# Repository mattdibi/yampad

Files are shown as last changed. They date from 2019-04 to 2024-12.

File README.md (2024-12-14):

<p align="center">
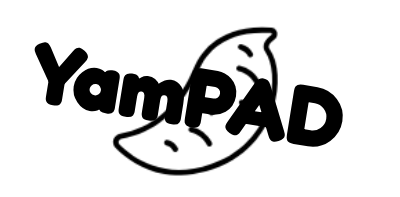
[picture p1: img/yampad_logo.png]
Yampad logo

QMK

</p>

<h3 align="center">The Yampad project repository</h3>

<div align="center">

[]()




</div>

---

The Yampad project is an open-source, [QMK (Quantum Mechanical Keyboard Firmware)](https://github.com/qmk/qmk_firmware) powered, hot-swappable, RGB-backlighted, OLED featured, mechanical numpad. This repository will be used to share information about the project and instruction on how to use and assemble the Yampad.

<p align="center">
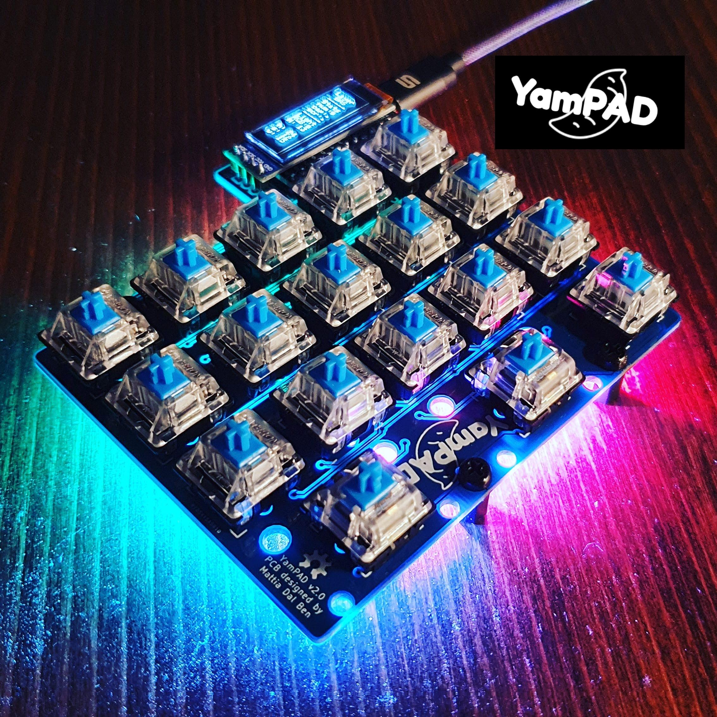
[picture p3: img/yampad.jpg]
Yampad PCB

</p>

**Designer's bio**: [Mattia Dal Ben (aka u/TiaMaT102)](mailto:matthewdibi@gmail.com) obtained a master's degree in Electrical Engineering with a specialization in Computer Science at the University of Udine. Currently works as a Software Engineer in R&D department for a big IoT and Embedded Computers company.

## Table of contents

- [Rationale](#rationale)
- [Default Layout](#default-layout)
- [Bill of materials](#bill-of-materials)
- [Assembly guide](#assembly-guide)
- [Firmware](#firmware)

## Rationale

<p align="center">
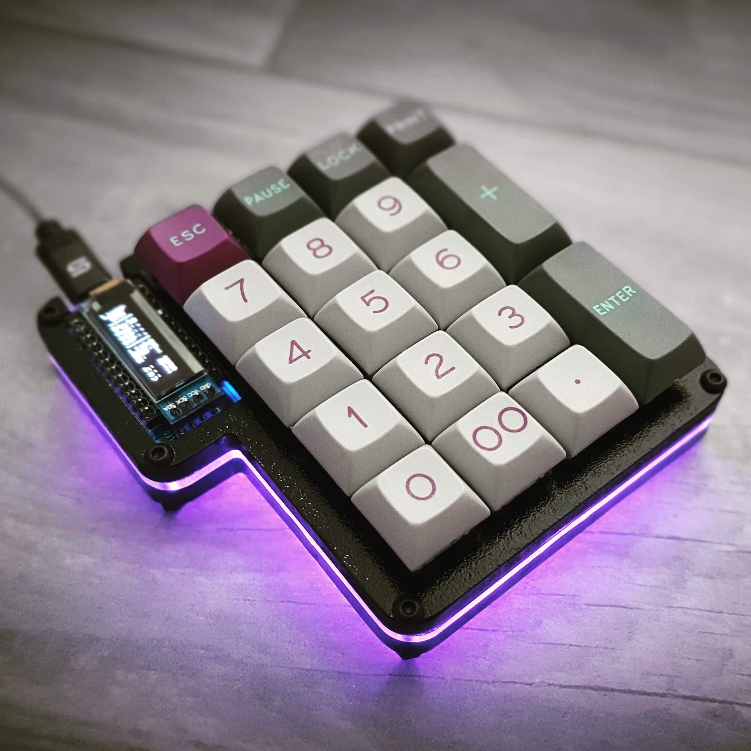
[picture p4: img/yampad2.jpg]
Yampad v2

</p>

The Yampad is a Macropad/Numpad which uses Cherry MX style mechanical switches laid out in the usual numeric pad layout. The only difference comes from the bottom row, which uses a 4 keys configuration, thus enabling the use of the macropad as a nav cluster.

The name comes from the acronym: **Y**et **A**nother **M**echanical num**PAD**, referring to the disruptive and innovative nature of the project.

The main goal of this project is to have a cheap, easy-to-build, feature-rich numpad which is completely open source.

Features:

- Cheap to build: the PCB can be manufactured for less than 1\$ per piece.
- Easy to source components.
- Easy to build.
- Hot swappable keys using _Kailh PCB sockets_.
- Arduino Pro Micro powered.
- QMK compatible.
- RGB backlighting support (optional).
- OLED 0.91" screen (optional).
- Completely open-source.

#### Useful links

- [YamPAD on Hackaday.io](https://hackaday.io/project/163491-yampad-feature-packed-open-source-macropad)

## Default Layout

<p align="center">
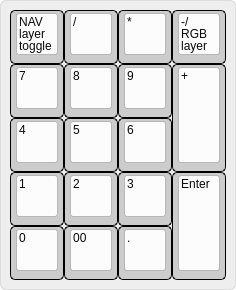
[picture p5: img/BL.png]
Layer 1 Yampad

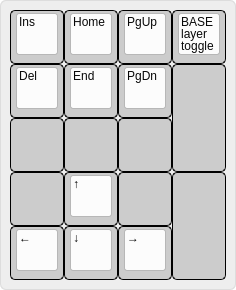
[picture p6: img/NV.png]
Layer 2 Yampad

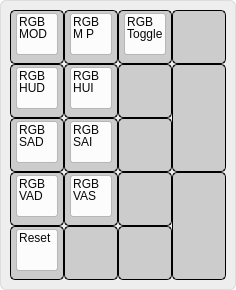
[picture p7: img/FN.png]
Layer 3 Yampad

</p>

## Bill of materials

| Qty | Item | Notes |
| --- | --- | --- |
| 1 | Arduino Pro Micro (ATmega32u4) | a.k.a. SparkFun Pro Micro |
| 18  | Cherry MX compatible swtiches | |
| 18  | SOD-123 1N4148/1N4148W diodes | |
| 18  | Kailh PCB sockets CPG151101S11 | |
| 9 | WS2812B RGB LEDs | Optional |
| 9 | SMD 0805 100nF capacitors | Optional (only required if WS2812B are installed) |
| 1 | I2C 0.91" 128\*32 OLED Display Module | The ones using SSD1306 driver IC over I2C |
| 1 | 6mm\*6mm button switch | |
| 1 | YamPAD PCB | [Order from PCBWay](https://www.pcbway.com/project/shareproject/YamPAD_mechanical_numpad.html) |
| 5 | M3 screws | |

## Assembly guide

There's no wrong order for the YamPAD assembly with the exception of the Arduino/OLED/ResetButton. Here I will suggest an order because I found more comfortable to solder the components this way.

1. Start with soldering the **WS2812 LEDs**. Start by applying solder to a pad, then heat it up while adding the component, finally solder the remaining pads.
2. Now add the **0805 100nF caps**. Use the same technique as before.
3. Add the **1N4148 diodes**.
4. Add the **CPG151101S11 Kailh PCB sockets**.
5. Add the **reset 6mm button switch**.
6. Add some electrical tape just to be sure.
7. Add the **Arduino Pro Micro** bottom side up.
8. Add the **OLED screen**
9. Move to the firmware section and you should be set!

### Assembly details

#### Step 1: WS2812 assembly

<p align="left">The LEDs have a direction, this is indicated by a small cut out corner showing a triangle on the LED itself that must align with a corner indicated on the PCB as a visible corner angle. Top left on images below.</p>
<p align="center">
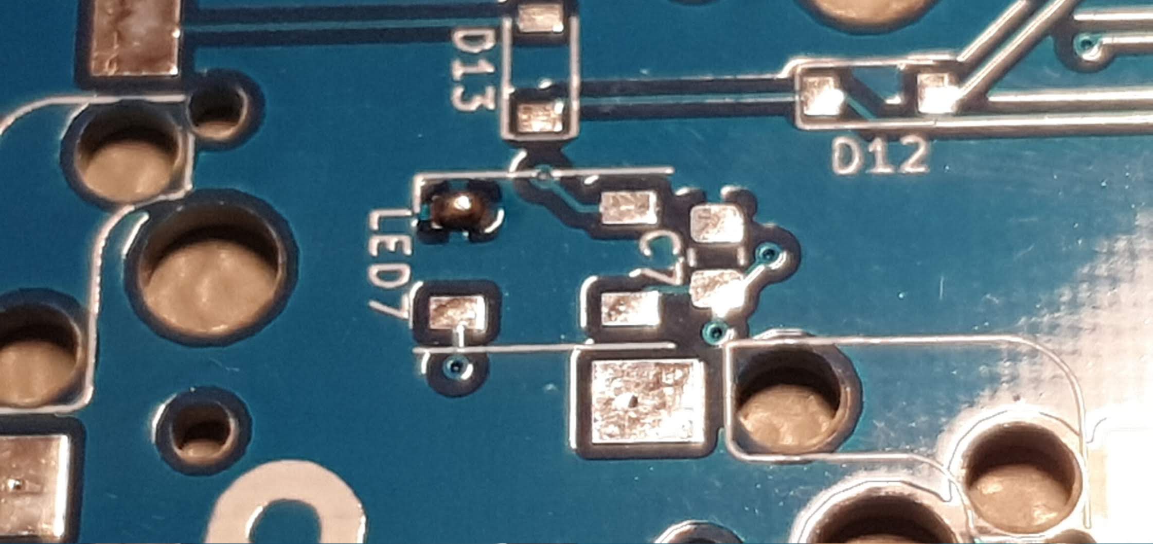
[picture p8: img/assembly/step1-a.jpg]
Step 1-a

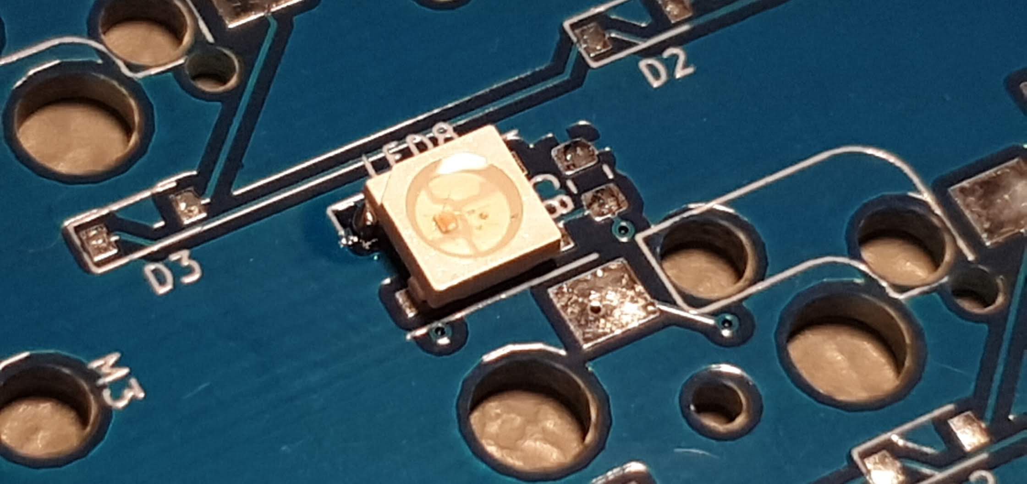
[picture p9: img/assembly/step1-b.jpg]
Step 1-b

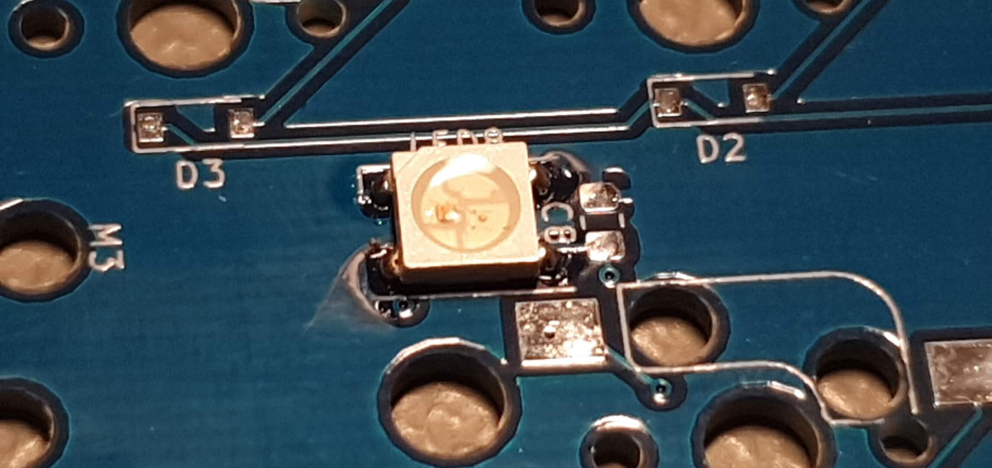
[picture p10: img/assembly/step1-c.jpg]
Step 1-c

</p>

#### Step 2: Capacitors assembly

<p align="center">
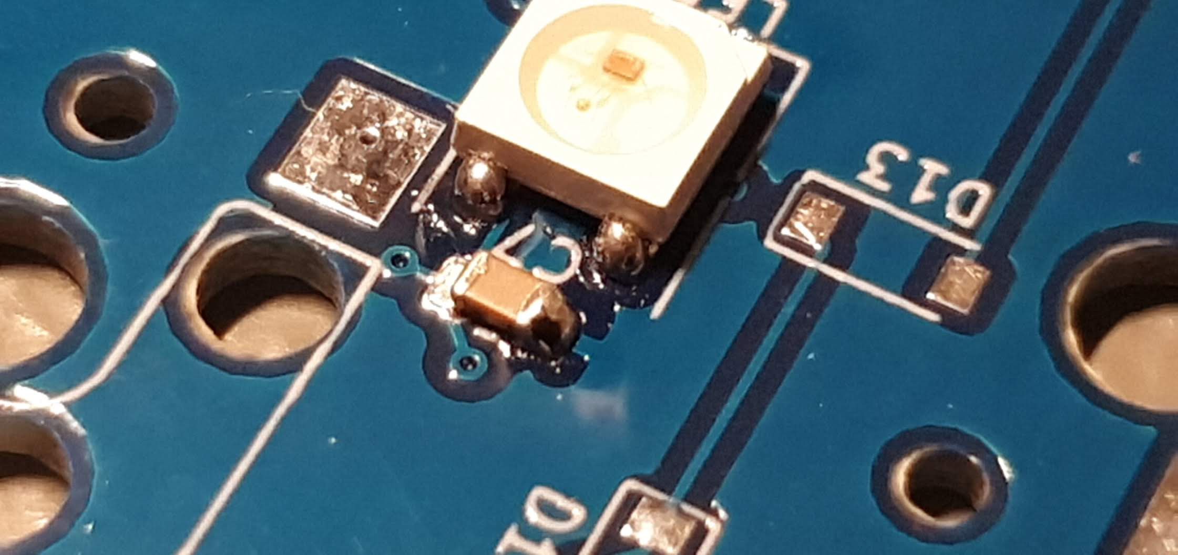
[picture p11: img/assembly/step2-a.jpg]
Step 2-a

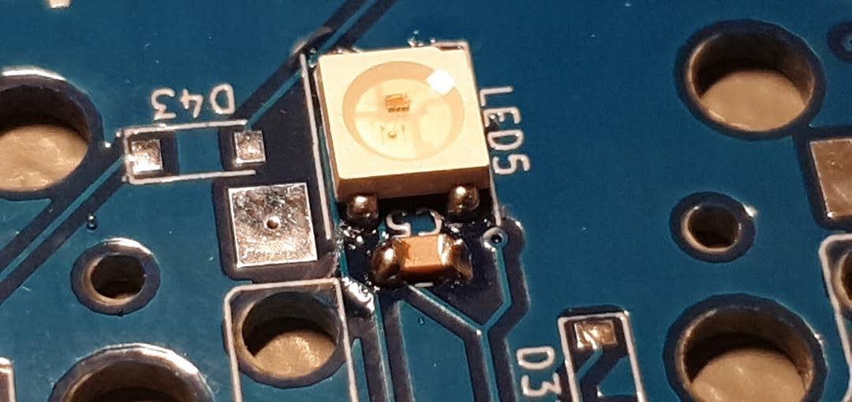
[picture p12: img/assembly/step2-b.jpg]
Step 2-b

</p>

#### Step 3: Diodes assembly

<p align="left">The diodes have a direction, the side indicated by the line on the diode must align to the closed side of the shape on the PCB. Left on the three images below.</p>
<p align="center">
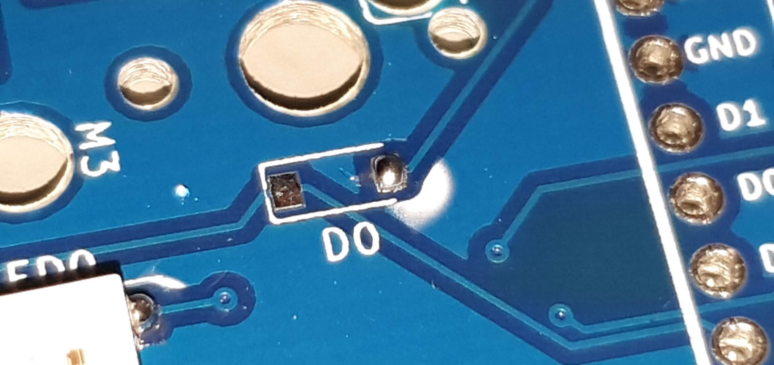
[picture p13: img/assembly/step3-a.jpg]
Step 3-a

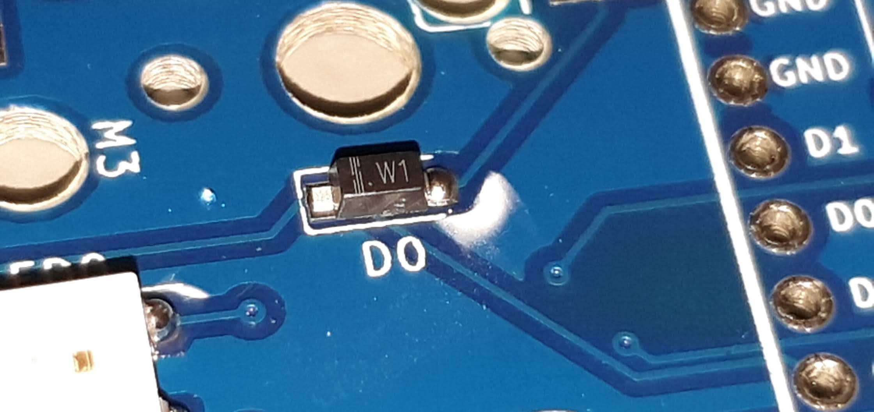
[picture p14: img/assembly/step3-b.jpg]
Step 3-b

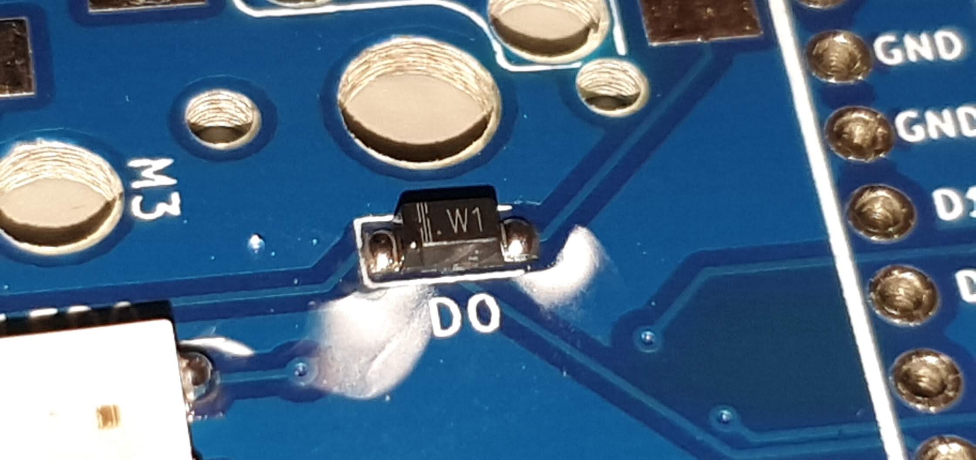
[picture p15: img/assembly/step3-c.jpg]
Step 3-c

</p>

#### Step 4: Kailh PCB sockets assembly

<p align="center">
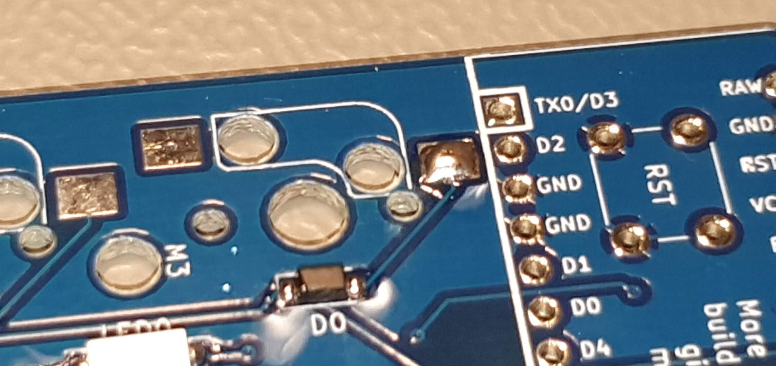
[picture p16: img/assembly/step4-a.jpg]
Step 4-a

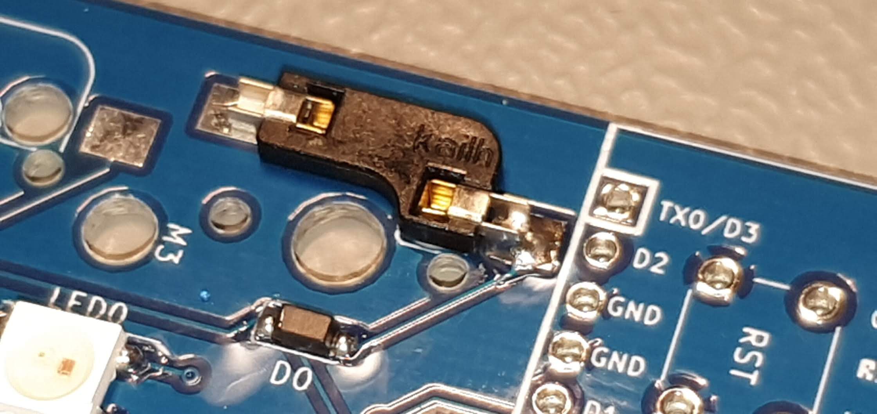
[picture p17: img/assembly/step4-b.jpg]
Step 4-b

</p>

#### Step 5: Reset switch

<p align="center">
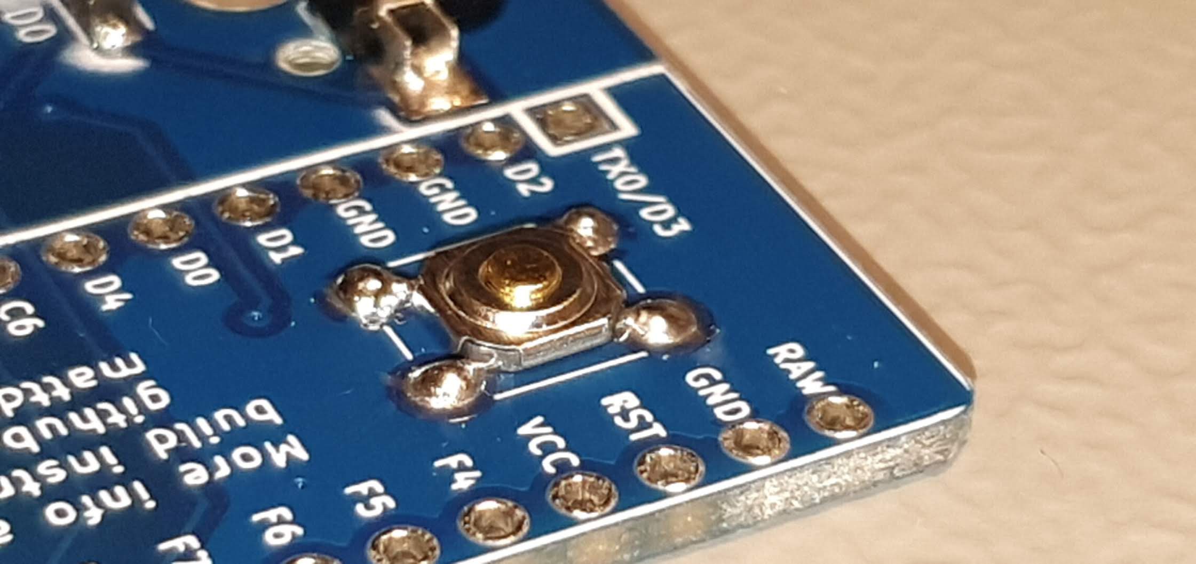
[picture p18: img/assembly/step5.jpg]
Step 5

</p>

#### Step 6: Electrical tape

<p align="center">
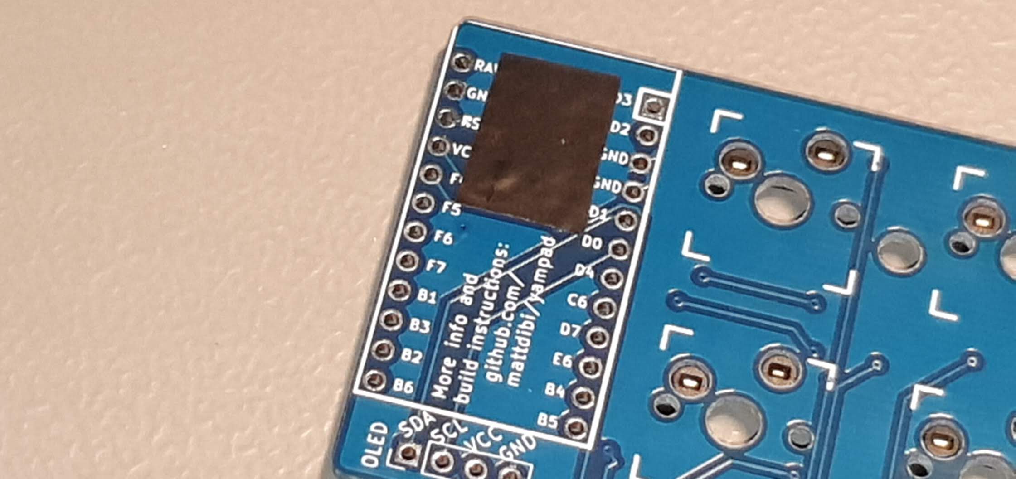
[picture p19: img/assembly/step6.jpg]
Step 6

</p>

#### Step 7: Arduino assembly

<p align="center">
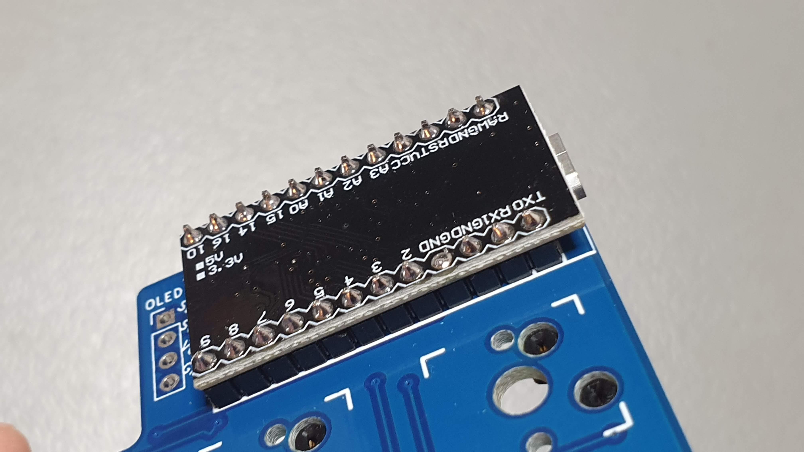
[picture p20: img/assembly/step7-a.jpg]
Step 7-a

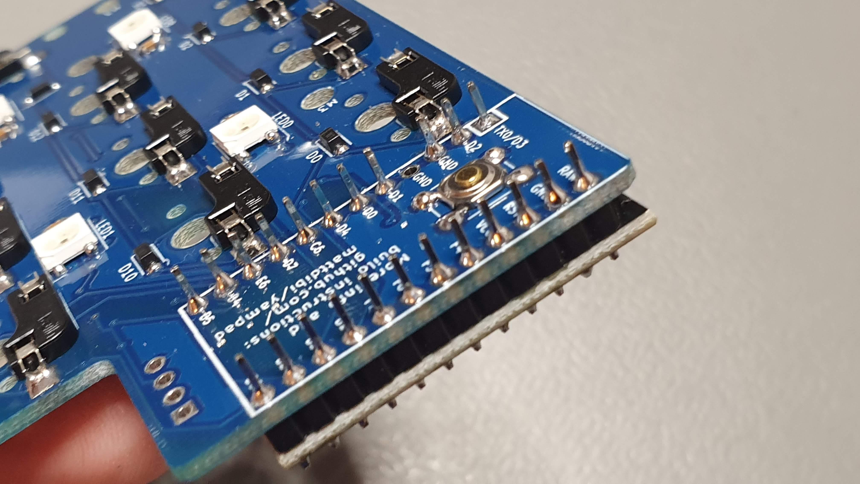
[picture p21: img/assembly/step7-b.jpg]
Step 7-b

</p>

## Firmware

The firmware is available through [QMK firmware repository](https://github.com/qmk/qmk_firmware/tree/master/keyboards/yampad). Make example for this keyboard (after setting up your build environment):

```sh
make yampad:default
```

Example of flashing this keyboard:

```sh
make yampad:default:flash
```

See the [build environment setup](https://docs.qmk.fm/#/getting_started_build_tools) and the [make instructions](https://docs.qmk.fm/#/getting_started_make_guide) for more information. Brand new to QMK? Start with our [Complete Newbs Guide](https://docs.qmk.fm/#/newbs).

#### Pre-built

I also added a pre-built .HEX file in the 'firmware/' folder [here](https://github.com/mattdibi/yampad/tree/master/firmware) to test the electronics.

#### Via Support

I also added a porting to via .HEX file in the 'firmware/via_support' folder [here](https://github.com/mattdibi/yampad/tree/master/firmware/via_support) to load use .json file in via apps.

#### Stacked Acrylic Case

<p align="center">
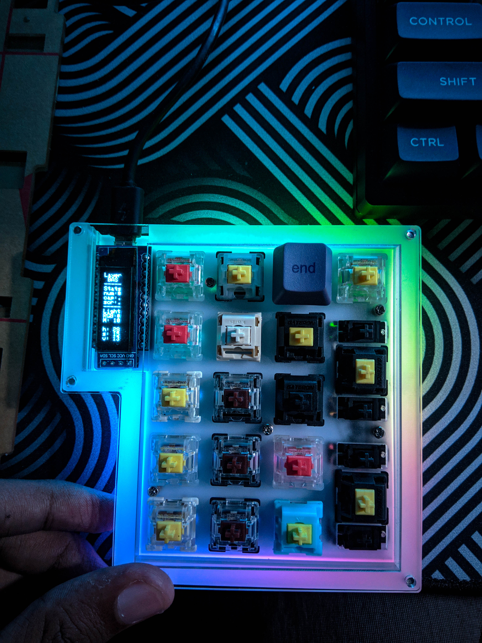
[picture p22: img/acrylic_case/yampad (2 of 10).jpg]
Yampad Acrylic Case

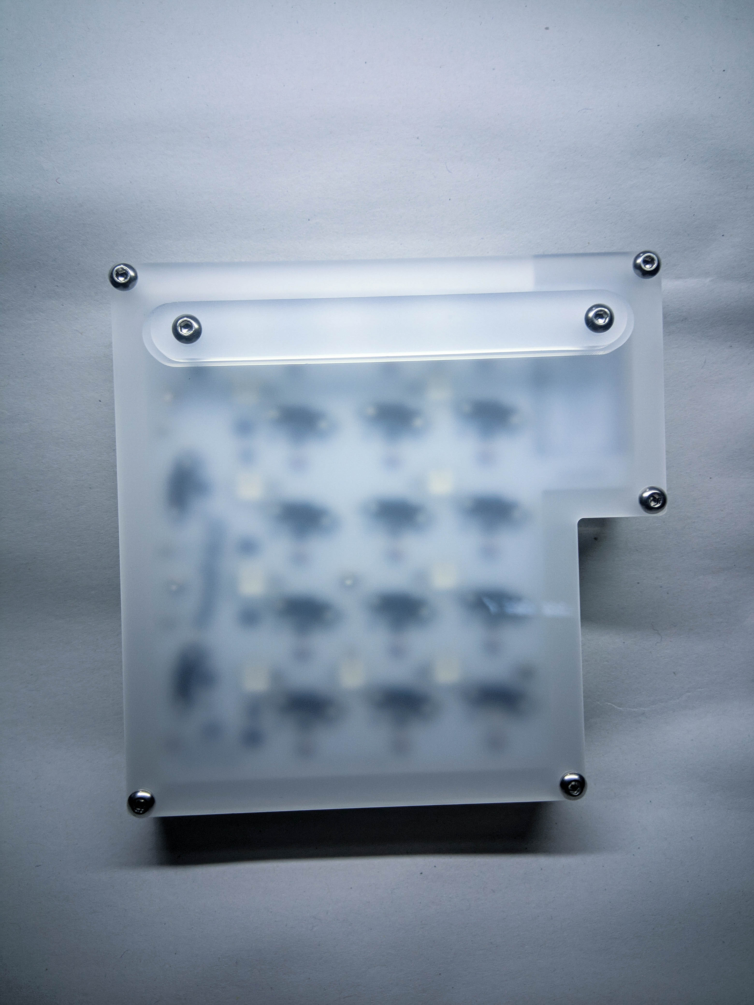
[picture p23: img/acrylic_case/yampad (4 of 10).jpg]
Yampad Acrylic Case

</p>

<p align="center">
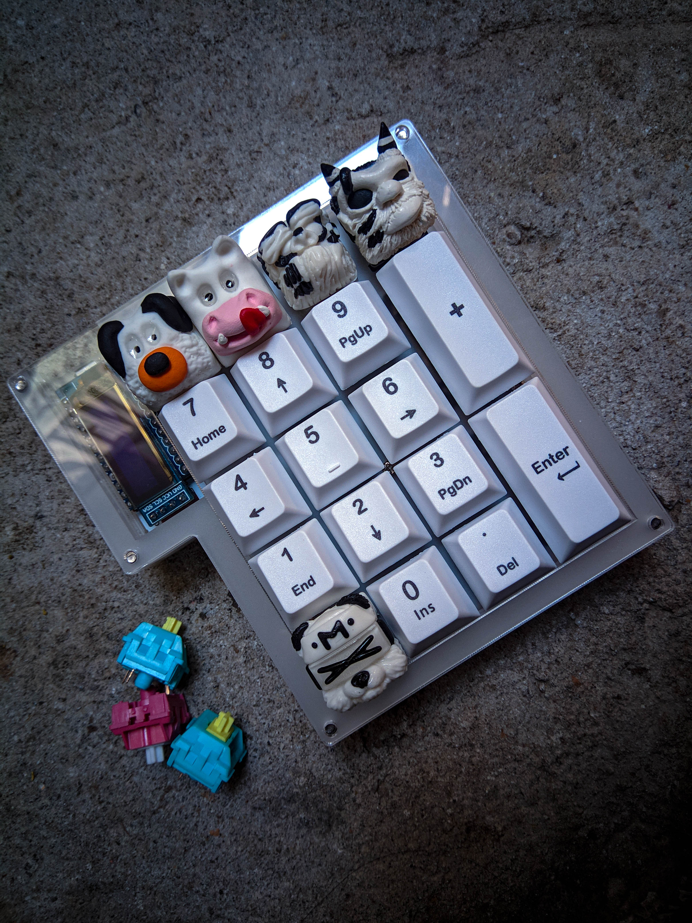
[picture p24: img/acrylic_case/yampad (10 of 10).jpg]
Yampad Acrylic Case

</p>

Acrylic case image gallery [here](https://github.com/mattdibi/yampad/tree/master/img/acrylic_case/).

### Donations

If you've read this far and found something useful, please consider donating to help me maintain and further develop this project.

<p align="center">
<a href="https://www.paypal.me/MattiaDalBen">Donate button</a>
</p>

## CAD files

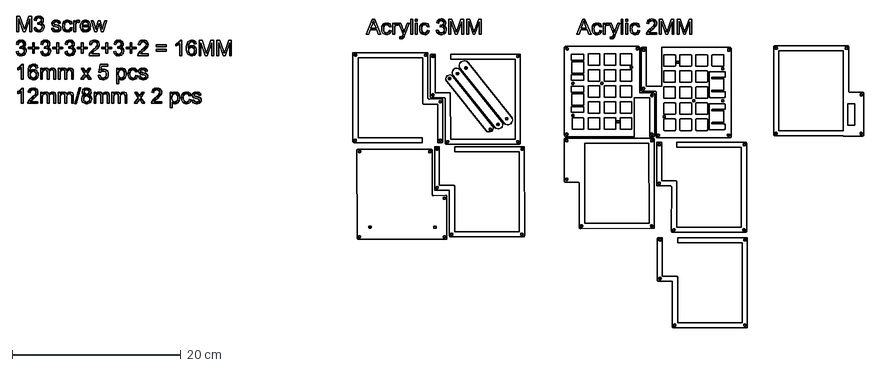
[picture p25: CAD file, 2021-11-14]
case/Stacked Acrylic/Stacked Acrylic Case.dxf
100.6 x 37.0 cm

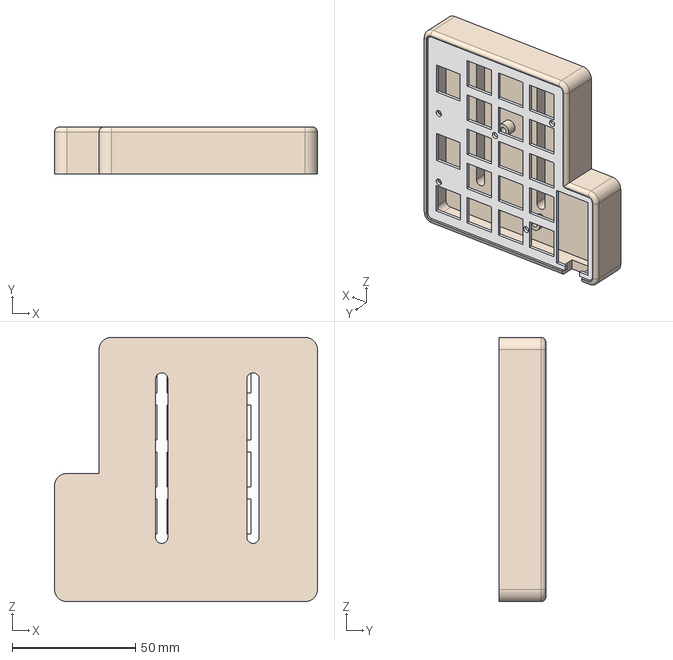
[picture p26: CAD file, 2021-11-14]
case/3D Print/yampad_v3-Fusion360.step
106.5 x 19.0 x 107.0 mm
Plate
Case

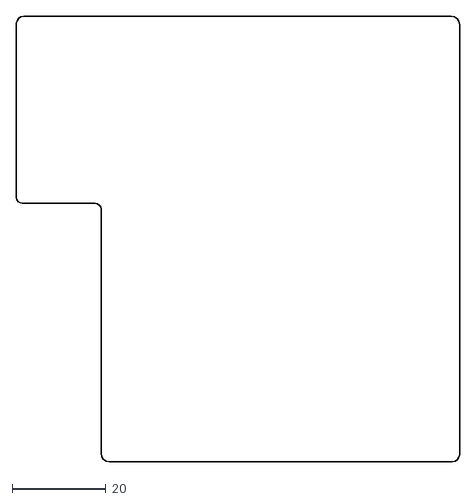
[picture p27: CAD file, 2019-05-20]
case/3D Print/yampad_v2-Edge.Cuts.dxf
94.5 x 95.0

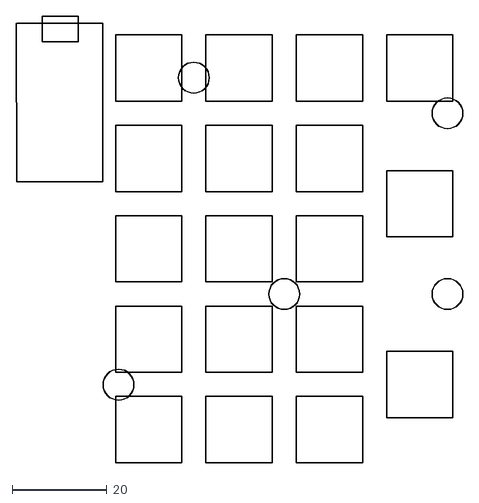
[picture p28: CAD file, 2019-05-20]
case/3D Print/yampad_v2-Eco2.User-screws.dxf
94.2 x 94.1

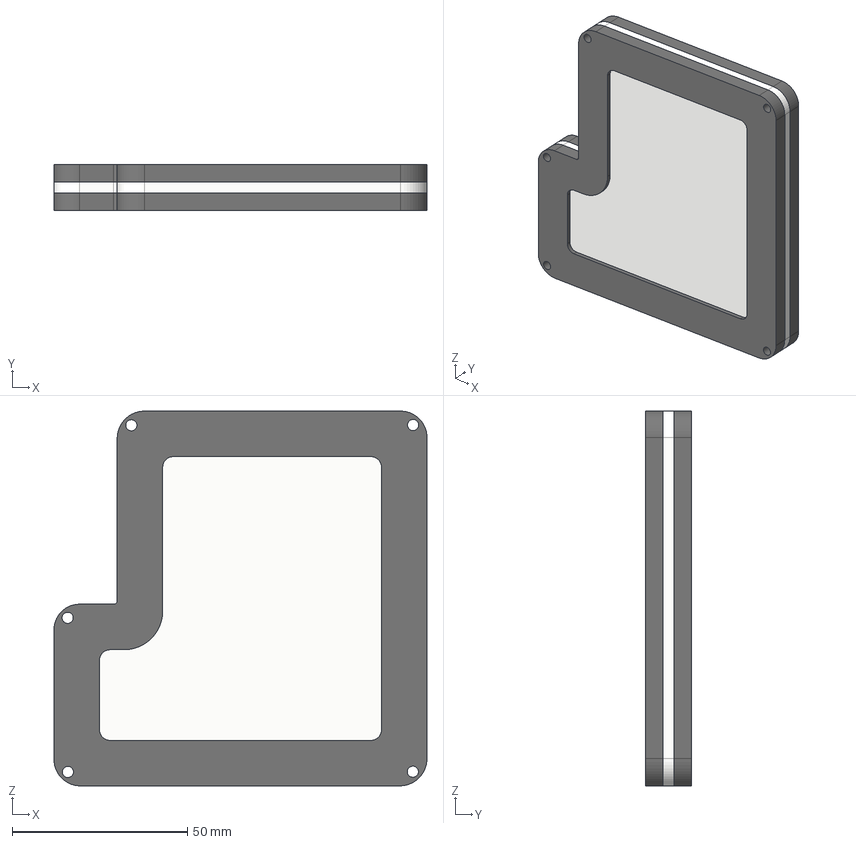
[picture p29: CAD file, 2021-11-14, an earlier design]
case/3D Print/yampad_v2-Fusion360.step
106.5 x 13.0 x 107.0 mm
MidLayer
TopLayer
BaseLayer
Window

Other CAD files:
case/3D Print/yampad_v2-Fusion360.f3d
case/3D Print/yampad_v3-Fusion360.f3d

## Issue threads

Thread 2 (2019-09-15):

unclear on which microcontroller should be used

landfillbaby, 2019-09-15:
"Arduino Pro Micro" isn't a real product
comparing the board here to the images in [this Stack Exchange answer](https://arduino.stackexchange.com/a/47161), it seems you actually meant the Sparkfun Pro Micro, but people may be confused and buy the actual Arduino Micro, which is obviously a different board and wouldn't work for this project without modifications
just thought it would be helpful to clarify

mattdibi, 2019-09-15:
Hi,

thank you for making me notice this. I never thought this could be misunderstood since the "unofficial" name of the Sparkfun Pro Micro seems to be Arduino Pro Micro (given what I find searching for it on eBay and Aliexpress). I'll make it clearer in the BOM anyway. ;)

Closed 2019-09-15.

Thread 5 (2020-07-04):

Are the hotswap sockets necessary?

Daveyr, 2020-07-04:
I'm looking at soldering the switches to the pcb directly. Is this possible or are the hotswap sockets necessary to affix the sockets?

mattdibi, 2020-07-05:
Hi,

the PCB only supports Kailh PCB sockets. You can't solder the switches directly.

Hope this helps.

Closed 2020-07-05.

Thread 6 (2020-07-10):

Process to print the case

Zeioth, 2020-07-10:
Please, could you explain the process to print the case? I uploaded  the files to [sculpteo](https://www.sculpteo.com)

    yampad_v2-Eco2.User-screws.dxf
    yampad_v2-Edge.Cuts.dxf

But I'm not sure how to proceed. I must print both files?
(I'm on linux so I don't have autocad to open the other 2 files)
Thank you.

Zeioth, 2020-07-10:
Ok after tweaking with fussion (web), I can see there are 2 versions:

V2: Made of 4 pieces.
V3: Made of 2 pieces (wooden base and steel top plate)

Could you please upload the pieces invidivially in .dxf, so I can order them, or know a linux program I can use to do it myself? Thank you.

Zeioth, 2020-07-10:
Ok got it,

Backplate: "yampad_v2-Edge.Cuts.dxf"
Top plate: "yampad_v2-Eco2.User-screws.dxf" -> But you must edit it on freecad before to send it for printing, to eliminate the arduino placeholder.

mattdibi, 2020-07-12:
Hi,

the .dxf are the outlines of the PCB and are there to help with the process of designing a new case for the Yampad. They can't be printed as is.

If you want a case you can start from the .f3d files which can be edited in Fusion360. Keep in mind that those two projects were thought to be CNC'd and not 3d printed though.

Zeioth, 2020-07-14:
Do you have any file dxf file with holes for stabilizers? I'm designing a case in steel, but I'm having a bad time with that. Cheers.

Zeioth, 2020-07-17:
This is still WIP but I'm designing a new cover in metal. Might post a pull request in the future when I have it in my hands.
[test.zip](https://github.com/mattdibi/yampad/files/4938210/test.zip)

Pretty excited, I just received my PCBs
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

mattdibi, 2020-07-19:
> Do you have any dxf file with holes for stabilizers? I'm designing a case in steel, but I'm having a bad time with that. Cheers.

@Zeioth You should be able to extract that file from the Kicad project file by selecting the correct layer. I'll try and extract it for you but I have very little free time lately.

Zeioth, 2020-07-20:
Thanks! Don't worry I managed to do it, I'm already making sure everything is correct before to send it for printing.

Closed 2020-12-07.

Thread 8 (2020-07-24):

Spark fun Pro Micro

GhastlyPompano, 2020-07-24:
Sparkfun's ProMicro comes in 2 variations. A 3.3v and a 5v. Which should I be using?

mattdibi, 2020-07-25:
Hi!

The pre-built firmware supports 5v/16MHz pro micros. If you order the 3.3v/8MHz you just need to change the `rules.mk` file to update [the CPU frequency](https://github.com/mattdibi/qmk_firmware/blob/6923c833ba1d2c0118f93a1a0708f2a898deba3c/keyboards/yampad/rules.mk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) and rebuild the firmware.

So, they're all supported but I suggest you to use the 5V version. :)

Closed 2020-07-25.

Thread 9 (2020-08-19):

Firmware won't compile

Daveyr, 2020-08-19:
Hi there,
I'm just trying to flash the microcontroller prior to populating the pcb and have come across a problem. I have set up my qmk environment in Ubuntu, cloned your fork of the qmk firmware and entered the command,

```
make yampad:default
```
However, I receive the following error:
make: *** No rule to make target 'yampad:default'.  Stop.

Please can you help? Looking at the keyboards subfolder there is no yampad folder within, in the latest commit.

Daveyr, 2020-08-19:
The yampad folder isn't present on master when cloned. However, it *is* there on a branch called yampad. Is the yampad branch default when you view it on Github and master is default when cloning?

Very confusing for someone who doesn't know git! Switching to yampad branch doesn't change the error message though.

mattdibi, 2020-08-19:
Hi,
yeah the yampad firmware lives only in my fork for now. Not yet pushed to the QMK main repository.
Regarding your error, after switching to the [yampad branch](https://github.com/mattdibi/qmk_firmware/tree/yampad) everything should work. Could you paste here the commands you issued for building?

Daveyr, 2020-08-20:
I can do one better and issue a merge request to the QMK-firmware repo if that works? I forked a recent version so it won't be too difficult. The steps I took are simplified below.

Set up my QMK environment in Linux as per https://docs.qmk.fm/#/newbs_getting_started
In a temp folder and using a terminal type, `git clone https://github.com/mattdibi/qmk_firmware`. We can delete this when finished.
`cd qmk_firmware` to change directory to qmk_firmware
Then `git checkout yampad`
Copy ./keyboards/yampad to ~/qmk_firmware/keyboards (this is the default location when setting up qmk in step 1)
Type `cd ~/qmk_firmware` to change directory there
Type `qmk compile -kb yampad -km default`
Type `make yampad:default:avrdude`

The steps above allowed me to successfully flash my pro micro. I haven't tested in a numpad yet. If I can arrange a merge with the original qmk_firmware then all other users would only have to do the last three steps.

Daveyr, 2020-10-12:
Steps above verified working on a real numpad.

nbaptist16, 2021-02-22:
I followed @Daveyr 's instructions and was able to compile, but am having trouble connecting to the programmer... this is the terminal output:

`nckmlb@xpso:~/qmk_firmware$ make yampad:default:avrdude
QMK Firmware 0.11.68
Making yampad with keymap default and target avrdude

avr-gcc (GCC) 5.4.0
Copyright (C) 2015 Free Software Foundation, Inc.
This is free software; see the source for copying conditions.  There is NO
warranty; not even for MERCHANTABILITY or FITNESS FOR A PARTICULAR PURPOSE.

Size before:
   text	   data	    bss	    dec	    hex	filename
      0	  25244	      0	  25244	   629c	.build/yampad_default.hex

Copying yampad_default.hex to qmk_firmware folder                                                   [OK]
Checking file size of yampad_default.hex                                                            [OK]
 * The firmware size is fine - 25244/28672 (88%, 3428 bytes free)
Detecting USB port, reset your controller now.....................................................................................................................
Device /dev/ttyACM0 has appeared; assuming it is the controller.
Waiting for /dev/ttyACM0 to become writable..

Connecting to programmer: .avrdude: butterfly_recv(): programmer is not responding

avrdude: butterfly_recv(): programmer is not responding
avrdude: butterfly_recv(): programmer is not responding
avrdude: butterfly_recv(): programmer is not responding
^Cmake[1]: *** [tmk_core/avr.mk:193: avrdude] Interrupt
make: *** [Makefile:522: yampad:default:avrdude] Interrupt
`

mattdibi, 2021-02-22:
@nbaptist16 Could [this](https://arduino.stackexchange.com/a/75189) be the issue? (Not firmware related BTW)

nbaptist16, 2021-02-23:
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

I found something that worked!

I ran the following two commands in a new terminal, but I'm pretty sure the second command alone is what did the job:

```

echo 'ATTRS{idVendor}=="2a03", ENV{ID_MM_DEVICE_IGNORE}="1"' | sudo tee /etc/udev/rules.d/77-arduino.rules

sudo udevadm trigger

```

Not entirely sure of why it worked, but I was able to flash the keyboard

```

avrdude: verifying ...
avrdude: 25244 bytes of flash verified

avrdude: safemode: Fuses OK (E:CB, H:D8, L:DE)

avrdude done.  Thank you.

```

Closed 2021-02-23.

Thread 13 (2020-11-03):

LEDs not working

alytle, 2020-11-03:
Hey Mattia,

Thanks for creating this project! I had a ton of fun with my build, as it's one of my first such projects. I managed to get everything working as expected, with the exception of the RGB lights.

I know you're busy and can't dive into fixing everyone's build, but do you have any high level suggestions on how to go about debugging the RGBs? Right now I can toggle the RGB on/off and see the status change on the OLED, but I'm getting no lights.

I had a few diodes which weren't properly secured, and those were easy to detect and repair because everything worked except for that switch, but the RGB is tougher because I'm getting nothing at all. I assume it's some sort of circuit where I have a broken connection somewhere?

These are the LEDs I used: https://www.digikey.ca/en/products/detail/sparkfun-electronics/COM-16346/11630211 and I was careful (I think) to properly align them.

I'll include a picture of my board case you can see something obviously wrong. Feel free to mock my terrible soldering.  :)

Thanks again and I appreciate any suggestions!

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

mattdibi, 2020-11-21:
Hi,

sorry for taking so long to answer. Since the LEDs are daisy chained (see schematic for details) I think that the connection is broken at some point and preventing any of them to light up. Check with a multimeter if they're receiving power and if signal il properly reaching every one of them.

[Here](https://www.luxalight.eu/sites/default/files/styles/max_650x650/public/legacy17/276/images/WS2812B_7.jpg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) you can find the pinout of the LEDs. Using a multimeter you should see 5V between VDD and VSS. The Dout from a LED should go to the Din of the subsequent LEDs.

Hope this helps.

alytle, 2020-11-24:
Thanks! I really appreciate the help. I'll take a stab at it on the weekend and see if I can figure out what went wrong. Hopefully it might help others.

alytle, 2020-12-02:
I had a look at the voltage across the RBGs. The VSS/VDD gives me 4.77V across all the LEDs. What's the correct way to measure DIn/Dout? I tried testing it across the individual RGBs and get inconsistent numbers, but that probably makes sense if it's supposed to be between LEDs.

Thanks again!

mattdibi, 2020-12-04:
> What's the correct way to measure DIn/Dout? I tried testing it across the individual RGBs and get inconsistent numbers, but that probably makes sense if it's supposed to be between LEDs.

These pins are used for data so you'll need an oscilloscope to see what's actually passing between them. I suggest you to check only continuity between them and the pin that is driving them.

mattdibi, 2020-12-06:
A correction:
> Since the LEDs are daisy chained (see schematic for details) I think that the connection is broken at some point and preventing any of them to light up.
In reality the LEDs should light up to the point the chain is broken. This may suggest that the chain is broken on the very first connection (arduino pin -> first LED), I would suggest a continuity check right on this connection.

alytle, 2020-12-07:
Hey, thanks for continuing to assist. I did add some solder to F4, though it was actually better in reality than it looked. I got no lights at first, but when I used the meter to test from F4 to Din on LED0, I suddenly got lights on RGB0 & 1! So it looks like I have my voltage pins soldered correctly but I've got a break in my data pins. I added more solder to Din on RGB0 and now these two work properly, without the meter bridge.

I was able to manually turn on all the rest of the LEDs using the meter. Some came on in groups, others individually. I find it a bit strange that I was perfect with the voltage, but so bad with the data pins. Is this because the data signal flows through the caps? They are by far the hardest when you're new to soldering, so perhaps a bunch of my caps are not connected properly?

Now that I've got a heartbeat I'll keep plugging away. So far I think the following info would be useful for others who try this build and run into similar issues:
- If some keys work and others don't, that's probably the diode connected to the misoperating key, resolder it
- If the LEDs dont come on:
    - Make sure you've enabled RGB through the firmware: RGB Layer + RGB Toggle
    - Check the VSS/VDD voltage on each RLED, it should be consistent for all, regardless of whether the lights are on
    - Check the signal line, starting at F4 and going to DIn on each LED, using a bridge if needed to get them to turn on

mattdibi, 2020-12-07:
>  Is this because the data signal flows through the caps?

Nope. Look at the schematic for details.

I’m glad you found what was wrong with the board. Have fun with it ;)

Closed 2020-12-07.

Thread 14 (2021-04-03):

issue flashing firmware

bilsch, 2021-04-03:
Hey,

not sure how to ask in a form or anything - missed it or just not a place to ask?

Whenever I try to flash the firmware I get the following error:

<details>

```
❯ make yampad:default:avrdude
QMK Firmware 0.6.396
Making yampad with keymap default and target avrdude

avr-gcc (Homebrew AVR GCC 9.3.0_2) 9.3.0
Copyright (C) 2019 Free Software Foundation, Inc.
This is free software; see the source for copying conditions.  There is NO
warranty; not even for MERCHANTABILITY or FITNESS FOR A PARTICULAR PURPOSE.

Size before:
   text	   data	    bss	    dec	    hex	filename
      0	  24856	      0	  24856	   6118	.build/yampad_default.hex

Copying yampad_default.hex to qmk_firmware folder                                                   [OK]
Checking file size of yampad_default.hex                                                            [OK]
 * The firmware size is fine - 24856/28672 (3816 bytes free)
Detecting USB port, reset your controller now..........
Device /dev/tty.usbmodem14101 has appeared; assuming it is the controller.
Waiting for /dev/tty.usbmodem14101 to become writable.

Connecting to programmer: .avrdude: butterfly_recv(): programmer is not responding

avrdude: butterfly_recv(): programmer is not responding
avrdude: butterfly_recv(): programmer is not responding
avrdude: butterfly_recv(): programmer is not responding
avrdude: butterfly_recv(): programmer is not responding
avrdude: butterfly_recv(): programmer is not responding
Found programmer: Id = ""; type =
    Software Version = .; Hardware Version = .
avrdude: butterfly_recv(): programmer is not responding
avrdude: butterfly_recv(): programmer is not responding
avrdude: error: buffered memory access not supported. Maybe it isn't
a butterfly/AVR109 but a AVR910 device?
avrdude: initialization failed, rc=-1
         Double check connections and try again, or use -F to override
         this check.

avrdude: butterfly_recv(): programmer is not responding
avrdude: error: programmer did not respond to command: leave prog mode
avrdude: butterfly_recv(): programmer is not responding
avrdude: error: programmer did not respond to command: exit bootloader

avrdude done.  Thank you.

make[1]: *** [avrdude] Error 1
make: Make finished with errors
*** [yampad:default:avrdude] Error 1
```

</details>

I tried copying the file from the repo and see the same result. I'm trying with these boards:

https://www.sparkfun.com/products/15795
https://www.sparkfun.com/products/12640

Any ideas? I have the same issue from linux, mac and windows. If I use arduino to upload blink works no problem

mattdibi, 2021-04-04:
Hi,

I already encountered this behavior on Linux and usually [this](https://arduino.stackexchange.com/a/75189) solved the issue. Does this help you?

It’s weird that with the Arduino IDE works...

bilsch, 2021-04-05:
Thats interesting but I have the issue from windows, linux and mac. I was able to get the firmware to apply to the usb micro variant but the usb-c one I have not gotten working.

Essentially I triggered the reset pin and extra time and that seemed to work. Feels like a timing issue in avrdude or elsewhere to me ( and/or a bug in the pro micro from sparkfun? )

Anyway I really appreciate the response and the project thanks!

Closed 2021-04-05.

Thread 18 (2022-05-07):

Diode

StarTakko, 2022-05-07:
Hi, I'm nowhere near ordering the PCB together with the components, but there are different 1N4148W with different amperage and voltage, do you know which one is correct? (I'm looking at lcsc)

Thank you!

mattdibi, 2022-05-13:
Hi there,
actually the ones you commonly find on ebay (advertised as "1A 1000V" or "100V 0.2A" ) should fit the bill. It's not a sensitive application really.

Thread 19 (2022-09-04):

Encoder support

karlmarxlopez, 2022-09-04:
I saw someone selling this with a rotary encoder support, when are you planning to release the PCB design with EC11 rotary?

mattdibi, 2022-09-05:
Hi there,
unfortunately I do not own the PCB design files since I didn't design that PCB. You should ask the seller.

Closed 2022-09-05.

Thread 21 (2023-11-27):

Rotary encoder support?

ScomosLastName, 2023-11-27:
Just finished assembling my Yampad v2 i got from custom kbd, it comes with the EC-11 rotary encoder but there's no support in the keymapping, it would be nice if i could get an updated keymap or an explanation on how to do it myself?

mattdibi, 2023-11-27:
Hello there @ScomosLastName,

I was not aware of this hardware revision. Please contact your seller for support: without knowing how the encoder is connected to the MCU there's nothing I can do.

Closed 2025-03-19.

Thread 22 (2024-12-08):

SMD or normal wire diodes

konisteel, 2024-12-08:
Hey i plan on making a pcb and is it possible to use normal wire diodes instead of smd ones? Mainly because it's hard to find it and hard to solder it.
Thanks

mattdibi, 2024-12-09:
Hello there @konisteel!

The PCB available in this repository doesn't support THT diodes (i.e. "wire diodes") only SMD ones.

konisteel, 2024-12-09:
Can't I solder the wires in the pads? It will still work the same right?
thanks

konisteel, 2024-12-09:
band the wires and cut them so a little bit is visible and solder that in the pads
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

konisteel, 2024-12-09:
Or maybe i can use these?
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
i dont know why they look like that lol

mattdibi, 2024-12-09:
> Can't I solder the wires in the pads? It will still work the same right? thanks

Well yeah, I wouldn't recommend it but it should work.

> Or maybe i can use these?

I think that that's a more exotic form factor than the officially supported one. Are you sure you want to push your luck with those?

The SOD-123 diodes I listed in the part list should be fairly easy to solder by hand...

konisteel, 2024-12-10:
Well the SOD-123 diodes for 1n4148 is not available in my country only the wire and exotic form factor
if you have extra time maybe you could edit the file to make it fit the wire diodes by adding holes to it?

kuro-codes, 2024-12-10:
> Well the SOD-123 diodes for 1n4148 is not available in my country only the wire and exotic form factor if you have extra time maybe you could edit the file to make it fit the wire diodes by adding holes to it?

I mean it is open source and you just could add them yourself if you need them.

mattdibi, 2024-12-10:
I think that 0805 1N4148 diodes should fit inside a SOD-123 footprint and should be readily available everywhere. IIRC I used those for my PCBs. Before purchasing them give it a proper look though.

> if you have extra time maybe you could edit the file to make it fit the wire diodes by adding holes to it?

I'm sorry but I cannot do that currently.

konisteel, 2024-12-10:
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

those also unfortunately are not available. Only wires and those exotic but 1 shop has them and it is double the price of normal ones so not a chance as I plan on building 20 of them

Closed 2024-12-09.

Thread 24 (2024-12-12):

Underglow & capasitors

konisteel, 2024-12-12:
Hey i just realized you used capacitors beside the ws2812b leds. If I don't install the leds than the capacitors are not necessary right?

konisteel, 2024-12-12:
Or i can use the leds without the capacitors? will it damage the pcb or anything i need to be ware of?

konisteel, 2024-12-12:
Or can you suggest some other capacitors that i can use? like 104 100nf

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

mattdibi, 2024-12-13:
Hi @konisteel,

you're correct: the capacitors are only required if you install the ws2812b leds. I should have put a note in the main readme about this.

konisteel, 2024-12-13:
Will there be any issues if I use ws2812b leds without the capacitors?

mattdibi, 2024-12-14:
> Will there be any issues if I use ws2812b leds without the capacitors?

The [datasheet](https://cdn-shop.adafruit.com/datasheets/WS2812B.pdf) application circuit uses them. I would not recommend running them without capacitors but I can't say for sure whether not installing them will introduce any issue. Do it at your own risk 🤷

Closed 2024-12-14.

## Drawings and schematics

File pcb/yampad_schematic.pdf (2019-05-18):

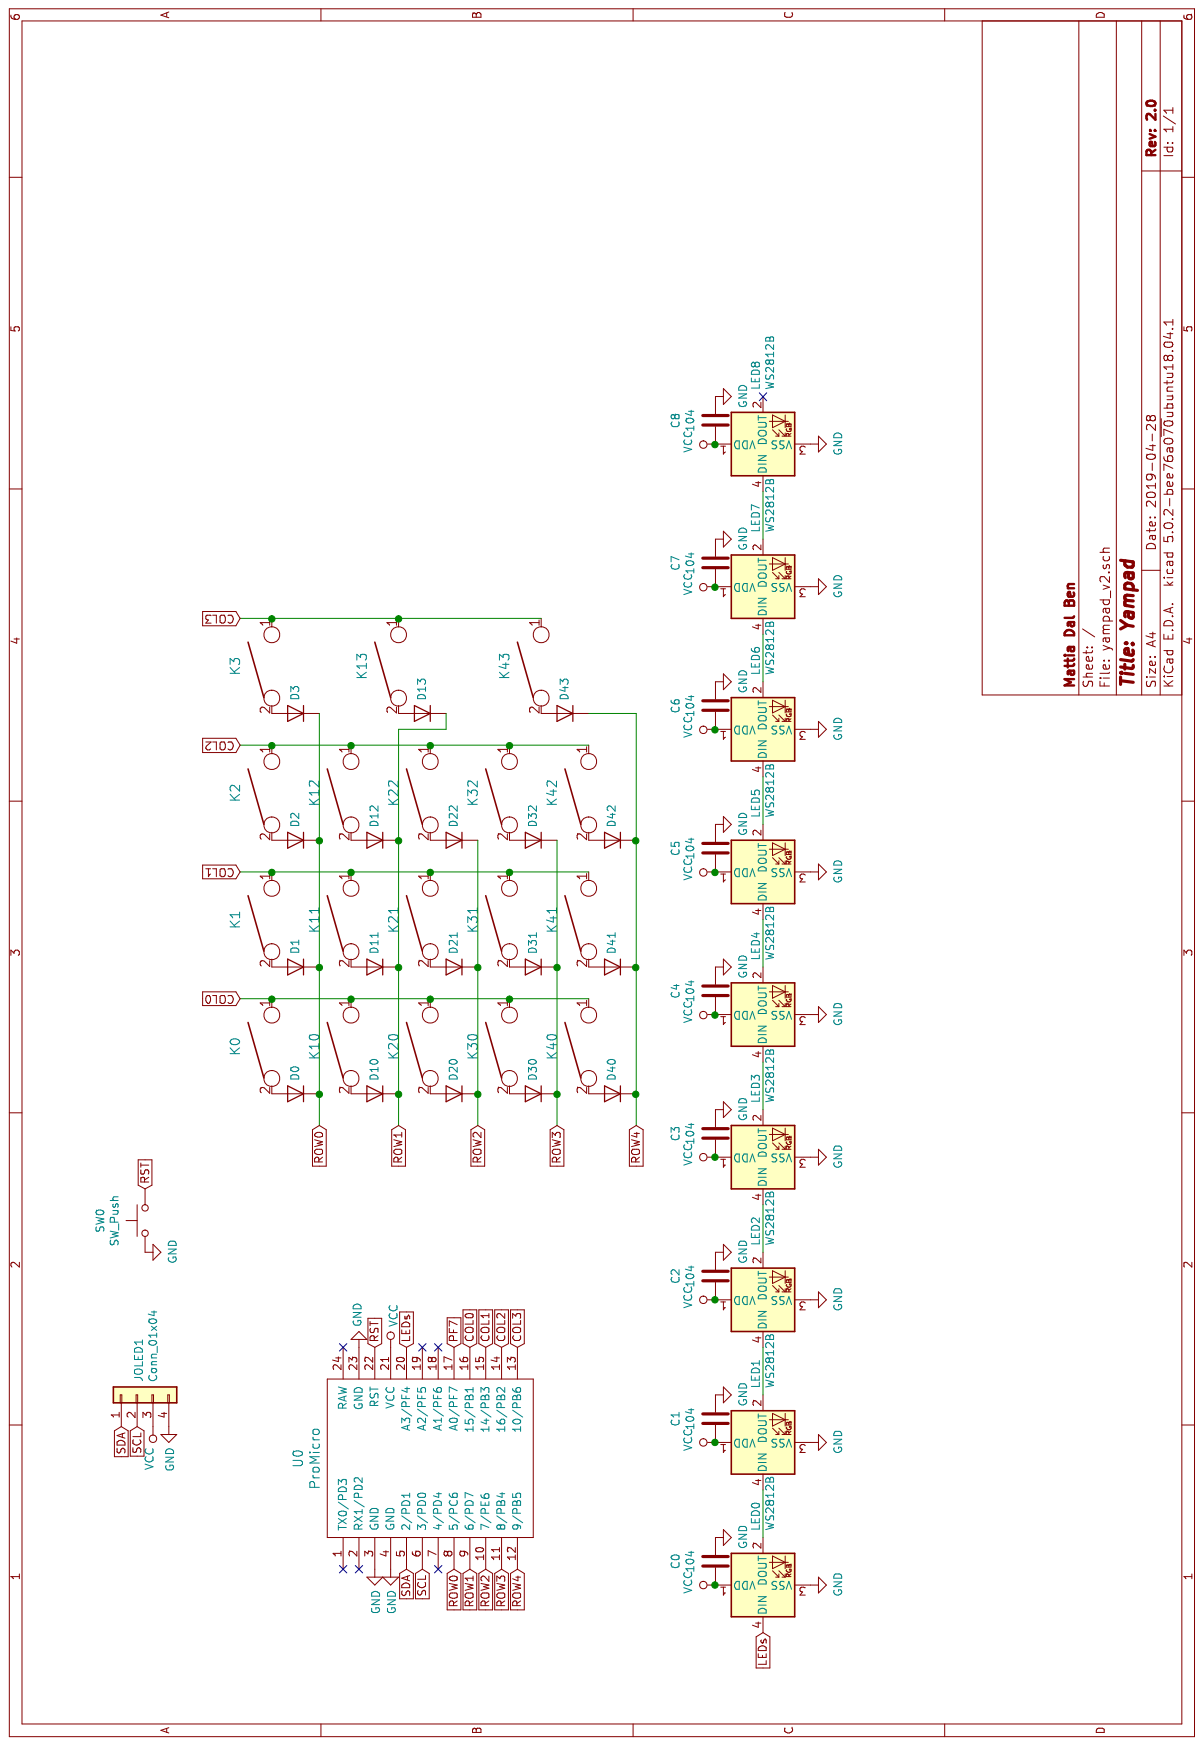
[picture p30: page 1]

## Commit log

2019-04-30 Added shameless donation button
2019-05-06 Added PCB pic
2019-05-18 Added PCB files
2019-05-20 Added BOM
2019-05-20 Added .dxf containing reference dimensions
    [yampad_v2-Eco2.User-screws.dxf, yampad_v2-Edge.Cuts.dxf]
2019-05-20 Added link for PCBWay ordering
2019-06-08 Added Fusion360 design file
    [yampad_v2-Fusion360.f3d]
2019-06-08 Assembly instructions (#1)
    * Added written instructions
    * Added stage pics
    * Added detailed instructions
    * Resized images
    * Added diodes installation details
    * Removed stages
    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
2019-09-01 Added wood and aluminium case files
    [yampad_v3-Fusion360.f3d]
2019-09-15 Clarified needed microcontroller in BOM
    See https://github.com/mattdibi/yampad/issues/2
2020-05-30 Added KiCAD sources (#4)
2020-10-03 Added details for LED and diode orientation (#10)
    * Update README.md
    * Update README.md
2021-01-23 Added yampad_v3-Fusion360.step file
    [yampad_v3-Fusion360.step]
2021-01-23 Added yampad_v2-Fusion360.step file
    [yampad_v2-Fusion360.step]
2021-01-23 Fixed missing plate in yampad_v3-Fusion360.step
    [yampad_v3-Fusion360.step]
2021-11-14 Add Via porting and Stacked Acrylic Case (#16)
    * add porting via
    * add Acrylic Case
    * fix location
    * location
    * location fix
    * add readme case and via information
    * change format case
    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
    [Stacked Acrylic Case.dxf, yampad_v2-Eco2.User-screws.dxf, yampad_v2-Edge.Cuts.dxf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]

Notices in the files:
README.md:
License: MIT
